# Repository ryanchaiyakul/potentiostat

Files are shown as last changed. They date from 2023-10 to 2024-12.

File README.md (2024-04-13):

# Potentiostat



I2BL potentiostat library and project.

# Goals

1. Create a library to easily program simple potentiostats for various voltammetry methods.
2. Create a collection of tools to develop future potentiostats.
3. Create a simulation suite to visualize and validate design decisions.

# Simulations

Go to the [README.md](CAD/LTSpice/README.md) in CAD/LTSpice folder.

# Tools

Go to the tools folder for a complete collection.

## CPE Models

Generate RC Train models of CPE elements to simulate how the readout circuit responds.

## PWL Voltammetry

Generate PWL files to pass into a voltage source to act as the DAC.

# Usage

```bash
# submodules are used in this repository for third party libraries
git clone --recurse-submodules git@github.com:ryanchaiyakul/potentiostat.git
```

1. Open the project in [VS Code](https://code.visualstudio.com/) with the [PlatformIO extension](https://marketplace.visualstudio.com/items?itemName=platformio.platformio-ide) installed.
2. Connect the Potentiostat to your computer by USB.
3. Navigate to the PlatformIO panel and click "Upload" or use the Command Palette (CNTL + SHIFT + P) and select "Upload".
4. Use the Serial Monitor in the terminal bar and select the baudrate of 230400.

# Features

- [x] Differential Pulse Voltammetry
- [x] Square Wave Voltammetry
- [ ] Cyclic Voltammetry
- [x] 300+ Hz SWV
- [ ] OTA Configuration
- [ ] EEPROM Persistent Configuration
- [ ] BLE Integration
- [x] Simple "Debug" Mode
- [x] Complete Analytics in "Debug" Mode
- [ ] Unit Testing Suite

# Development Guide

Create a valid class that inherits from Voltammetry defined in [Voltammetry.h](lib/Voltammetry/Voltammetry.h).

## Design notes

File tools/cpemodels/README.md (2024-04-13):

# CPE Models

Generate an RC Train that models a CPE device.

Documentation WIP

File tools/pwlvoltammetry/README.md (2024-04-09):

# PWL Voltammetry

A python tool to generate .pwl files of DAC voltages for LTSpice simulations.

## Usage

Edit config.py to the voltammetry parameters and run main.py

```bash
python main.py
```

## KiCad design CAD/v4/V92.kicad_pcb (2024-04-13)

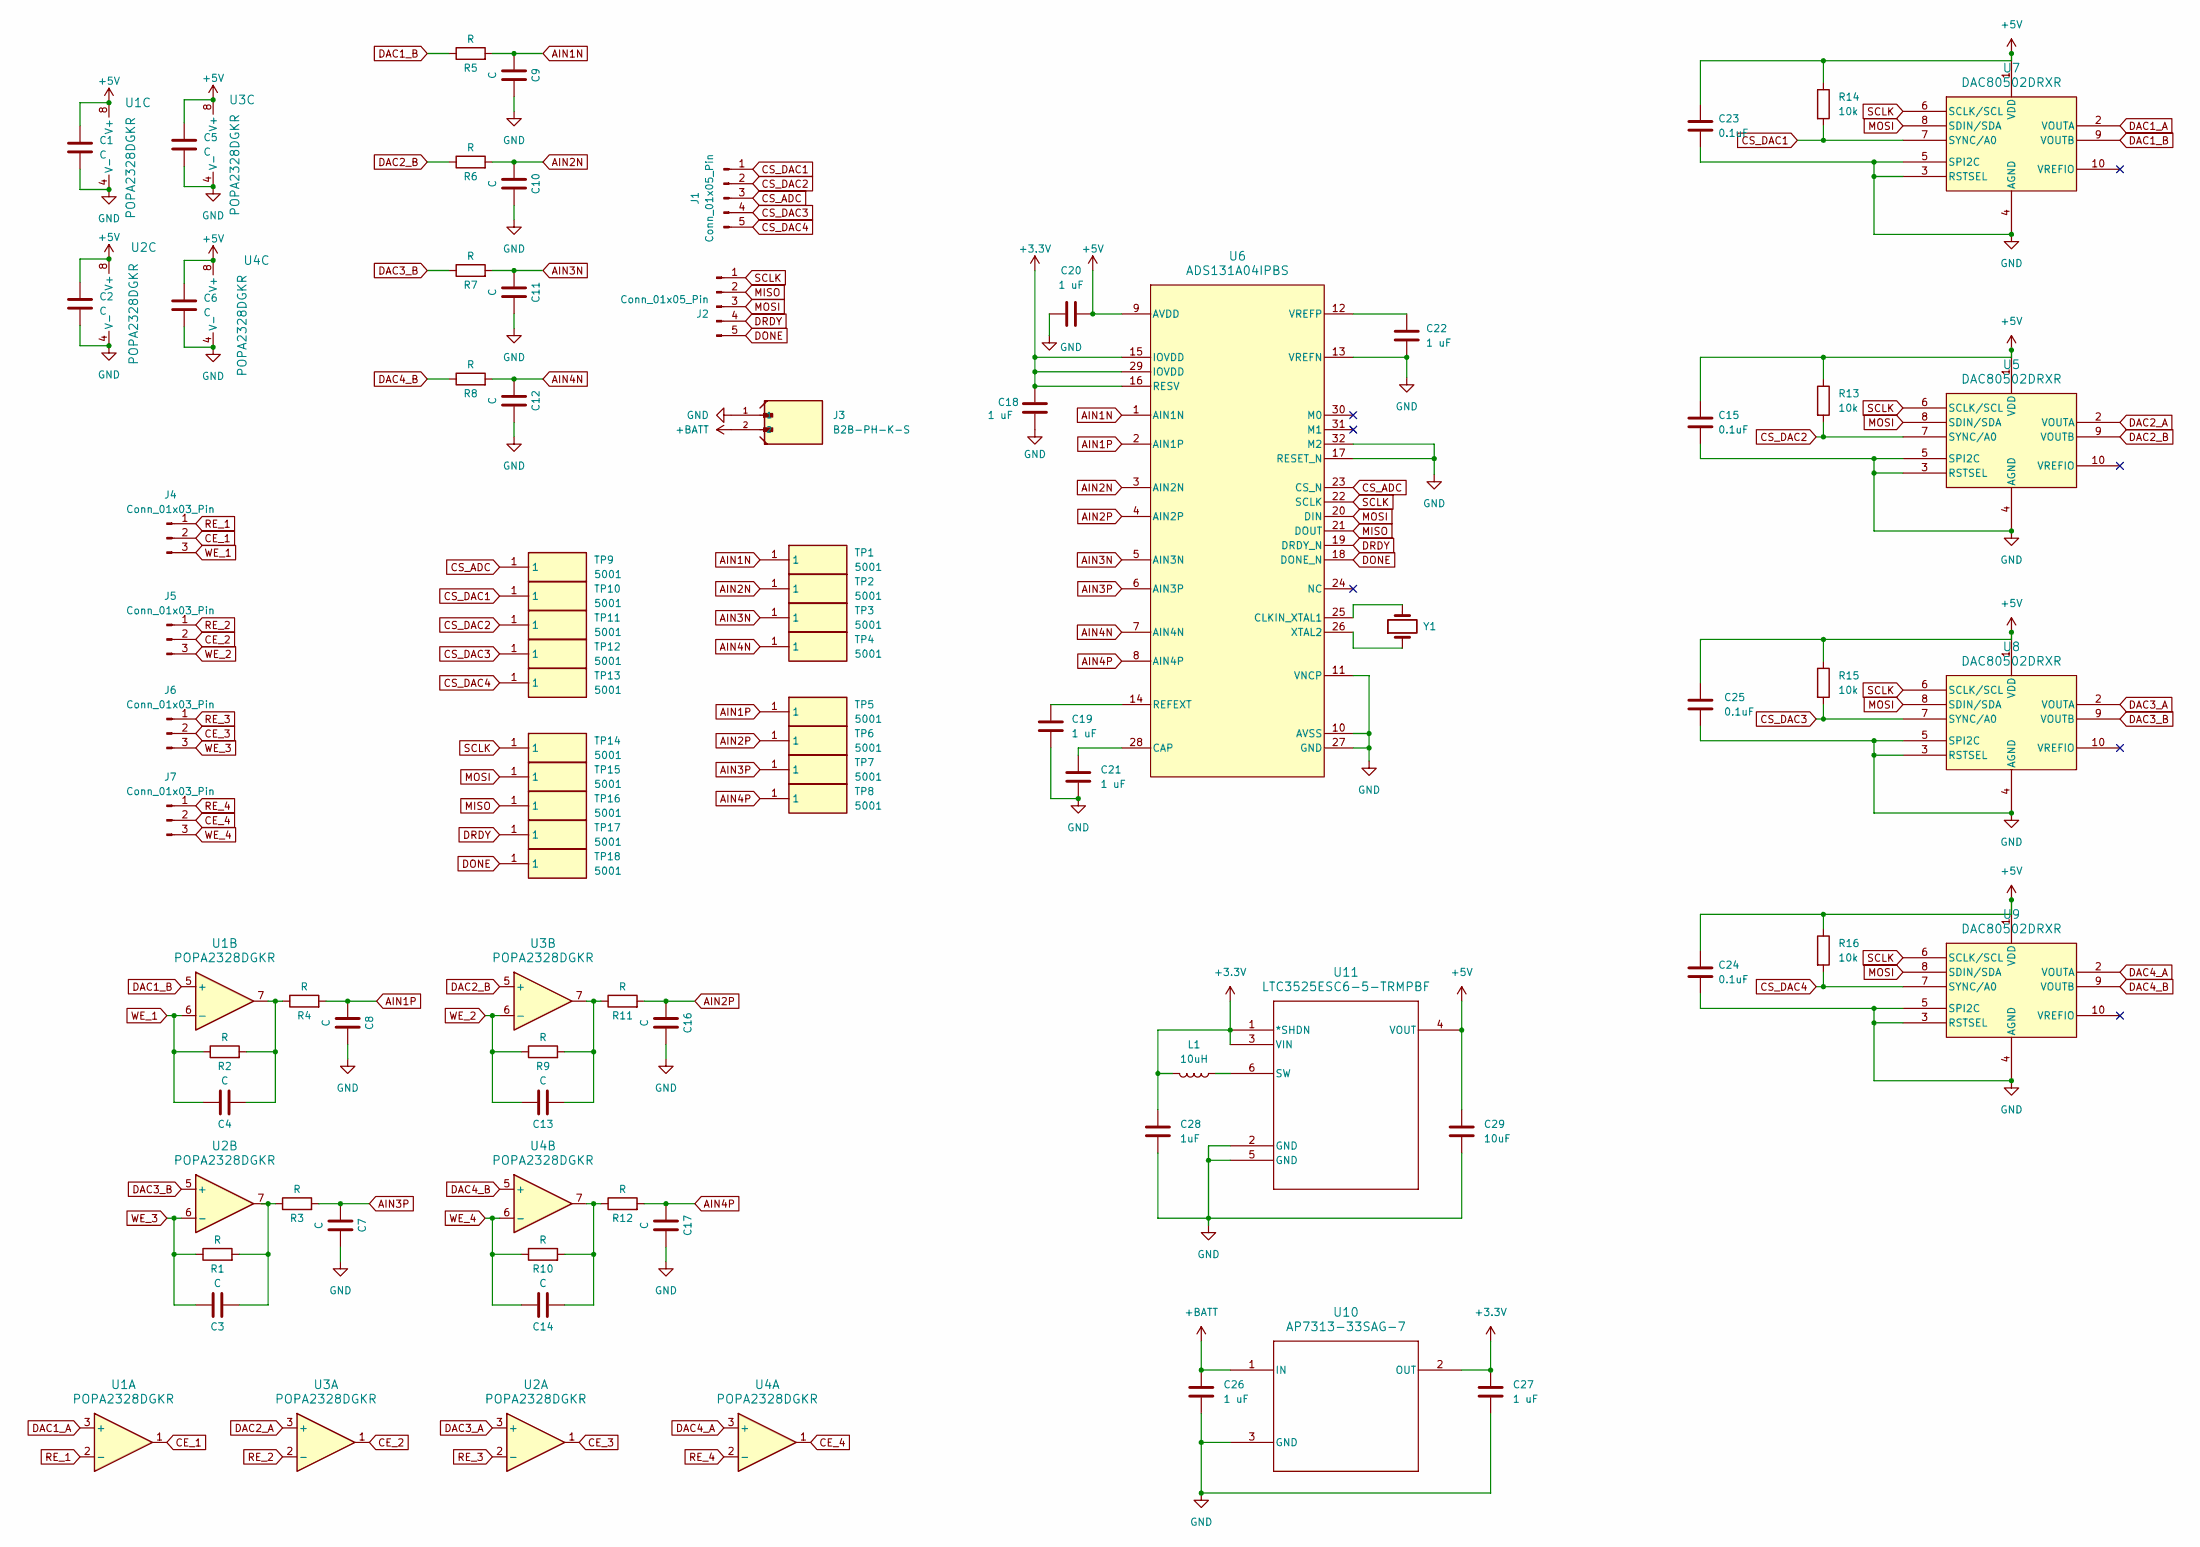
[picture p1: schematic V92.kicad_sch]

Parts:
C1, C2, C3, C4, C5, C6, C7, C8, C9, C10, C11, C12, C13, C14, C16, C17: C; C_0603_1608Metric_Pad1.08x0.95mm_HandSolder
C15, C23, C24, C25: 0.1uF; C_0603_1608Metric_Pad1.08x0.95mm_HandSolder
C18, C19, C20, C21, C22, C26, C27: 1 uF; C_0603_1608Metric_Pad1.08x0.95mm_HandSolder
C28: 1uF; C_0603_1608Metric_Pad1.08x0.95mm_HandSolder
C29: 10uF; C_0603_1608Metric_Pad1.08x0.95mm_HandSolder
J1, J2: Conn_01x05_Pin; PinHeader_1x05_P2.54mm_Vertical
J3: B2B-PH-K-S; JST_B2B-PH-K-S
J4, J5, J6, J7: Conn_01x03_Pin; PinHeader_1x03_P2.54mm_Vertical
L1: 10uH; L_0603_1608Metric_Pad1.05x0.95mm_HandSolder
R1, R2, R3, R4, R5, R6, R7, R8, R9, R10, R11, R12: R; R_0603_1608Metric_Pad0.98x0.95mm_HandSolder
R13, R14, R15, R16: 10k; R_0603_1608Metric_Pad0.98x0.95mm_HandSolder
TP1, TP2, TP3, TP4, TP5, TP6, TP7, TP8, TP9, TP10, TP11, TP12, TP13, TP14, TP15, TP16, TP17, TP18: 5001; 5000; Mouser Part Number 534-5001
U1, U2, U3, U4: POPA2328DGKR; SO8_DGK_TEX
U5, U7, U8, U9: DAC80502DRXR; SON_02DRXR_TEX
U6: ADS131A04IPBS; PBS0032A_N
U10: AP7313-33SAG-7; SOT-23_DIO
U11: LTC3525ESC6-5-TRMPBF; SC70-SC6_LIT
Y1: Crystal; Crystal_SMD_HC49-SD

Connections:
+3.3V: C18.1, C27.1, C28.1, L1.2, U6.15 (IOVDD), U6.16 (RESV), U6.29 (IOVDD), U10.2 (OUT), U11.1 (*SHDN), U11.3 (VIN)
+5V: C1.1, C2.1, C5.1, C6.1, C15.1, C20.1, C23.1, C24.1, C25.1, C29.1, R13.1, R14.1, R15.1, R16.1, U1.8 (V+), U2.8 (V+), U3.8 (V+), U4.8 (V+), U5.1 (VDD), U6.9 (AVDD), U7.1 (VDD), U8.1 (VDD), U9.1 (VDD), U11.4 (VOUT)
+BATT: C26.1, J3.2, U10.1 (IN)
AIN1N: C9.2, R5.2, TP1.1, U6.1 (AIN1N)
AIN1P: C8.2, R4.2, TP5.1, U6.2 (AIN1P)
AIN2N: C10.2, R6.2, TP2.1, U6.3 (AIN2N)
AIN2P: C16.2, R11.2, TP6.1, U6.4 (AIN2P)
AIN3N: C11.2, R7.2, TP3.1, U6.5 (AIN3N)
AIN3P: C7.2, R3.2, TP7.1, U6.6 (AIN3P)
AIN4N: C12.2, R8.2, TP4.1, U6.7 (AIN4N)
AIN4P: C17.2, R12.2, TP8.1, U6.8 (AIN4P)
CE_1: J4.2, U1.1
CE_2: J5.2, U3.1
CE_3: J6.2, U2.1
CE_4: J7.2, U4.1
CS_ADC: J1.3, TP9.1, U6.23 (CS_N)
CS_DAC1: J1.1, R14.2, TP10.1, U7.7 (SYNC/A0)
CS_DAC2: J1.2, R13.2, TP11.1, U5.7 (SYNC/A0)
CS_DAC3: J1.4, R15.2, TP12.1, U8.7 (SYNC/A0)
CS_DAC4: J1.5, R16.2, TP13.1, U9.7 (SYNC/A0)
DAC1_A: U1.3 (+), U7.2 (VOUTA)
DAC1_B: R5.1, U1.5 (+), U7.9 (VOUTB)
DAC2_A: U3.3 (+), U5.2 (VOUTA)
DAC2_B: R6.1, U3.5 (+), U5.9 (VOUTB)
DAC3_A: U2.3 (+), U8.2 (VOUTA)
DAC3_B: R7.1, U2.5 (+), U8.9 (VOUTB)
DAC4_A: U4.3 (+), U9.2 (VOUTA)
DAC4_B: R8.1, U4.5 (+), U9.9 (VOUTB)
DONE: J2.5, TP18.1, U6.18 (DONE_N)
DRDY: J2.4, TP17.1, U6.19 (DRDY_N)
GND: C1.2, C2.2, C5.2, C6.2, C7.1, C8.1, C9.1, C10.1, C11.1, C12.1, C15.2, C16.1, C17.1, C18.2, C19.2, C20.2, C21.2, C22.2, C23.2, C24.2, C25.2, C26.2, C27.2, C28.2, C29.2, J3.1, U1.4 (V-), U2.4 (V-), U3.4 (V-), U4.4 (V-), U5.3 (RSTSEL), U5.4 (AGND), U5.5 (SPI2C), U6.10 (AVSS), U6.11 (VNCP), U6.13 (VREFN), U6.17 (RESET_N), U6.27 (GND), U6.32 (M2), U7.3 (RSTSEL), U7.4 (AGND), U7.5 (SPI2C), U8.3 (RSTSEL), U8.4 (AGND), U8.5 (SPI2C), U9.3 (RSTSEL), U9.4 (AGND), U9.5 (SPI2C), U10.3 (GND), U11.2 (GND), U11.5 (GND)
MISO: J2.2, TP16.1, U6.21 (DOUT)
MOSI: J2.3, TP15.1, U5.8 (SDIN/SDA), U6.20 (DIN), U7.8 (SDIN/SDA), U8.8 (SDIN/SDA), U9.8 (SDIN/SDA)
unnamed: C3.2, R1.2, R3.1, U2.7
unnamed: C4.2, R2.2, R4.1, U1.7
unnamed: C13.2, R9.2, R11.1, U3.7
unnamed: C14.2, R10.2, R12.1, U4.7
unnamed: C21.1, U6.28 (CAP)
unnamed: U6.25 (CLKIN_XTAL1), Y1.2
unnamed: C19.1, U6.14 (REFEXT)
unnamed: C22.1, U6.12 (VREFP)
unnamed: U6.26 (XTAL2), Y1.1
unnamed: L1.1, U11.6 (SW)
RE_1: J4.1, U1.2 (-)
RE_2: J5.1, U3.2 (-)
RE_3: J6.1, U2.2 (-)
RE_4: J7.1, U4.2 (-)
SCLK: J2.1, TP14.1, U5.6 (SCLK/SCL), U6.22 (SCLK), U7.6 (SCLK/SCL), U8.6 (SCLK/SCL), U9.6 (SCLK/SCL)
WE_1: C4.1, J4.3, R2.1, U1.6 (-)
WE_2: C13.1, J5.3, R9.1, U3.6 (-)
WE_3: C3.1, J6.3, R1.1, U2.6 (-)
WE_4: C14.1, J7.3, R10.1, U4.6 (-)

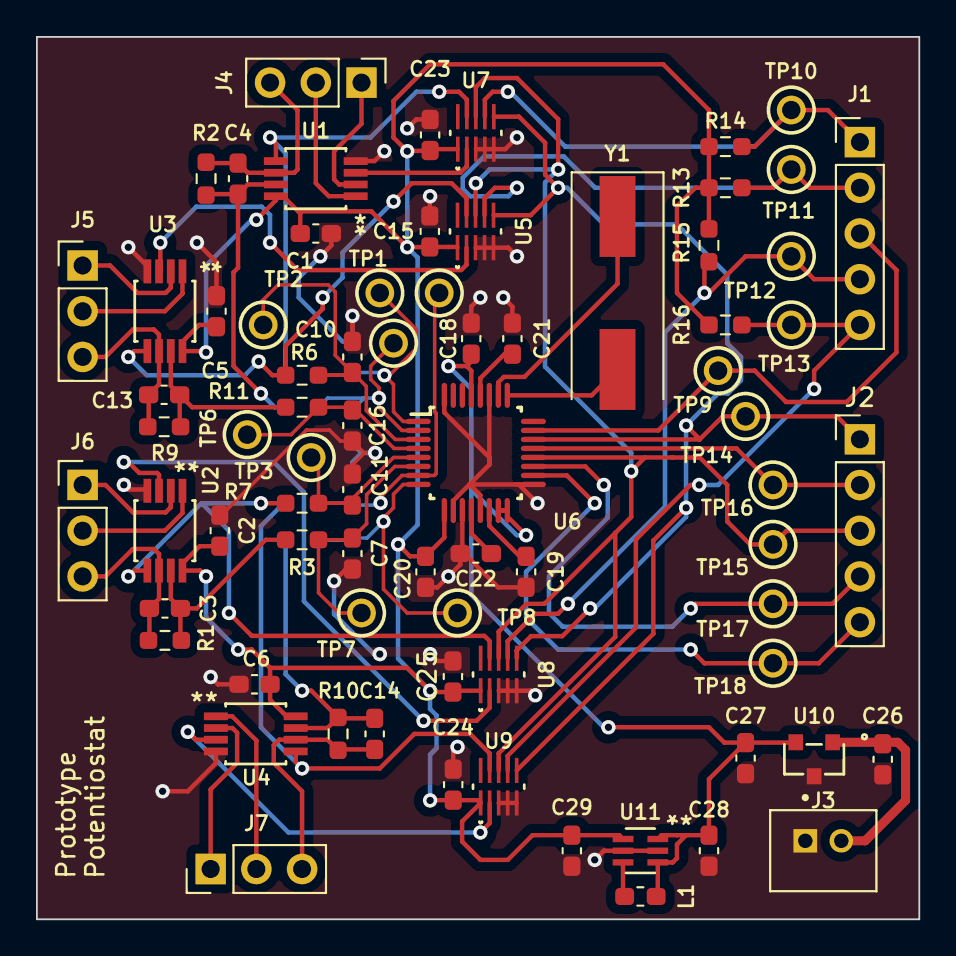
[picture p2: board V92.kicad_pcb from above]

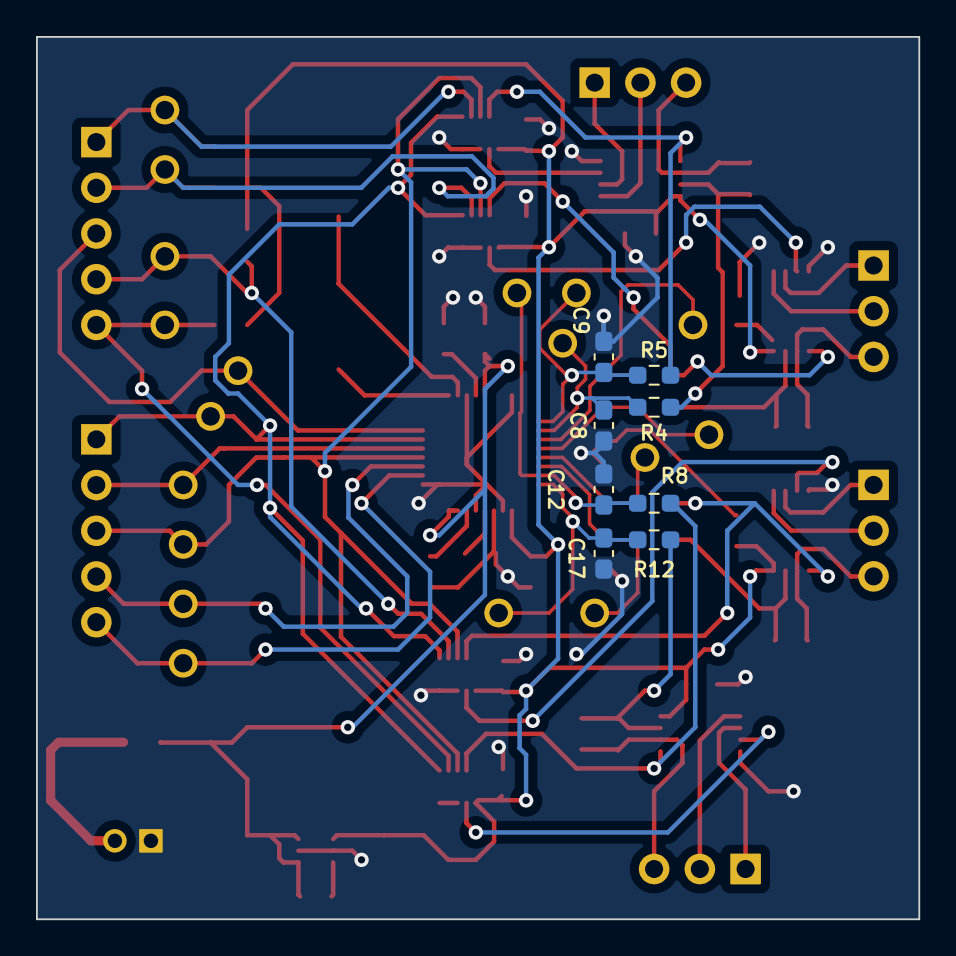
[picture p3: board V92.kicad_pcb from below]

Board: 2 copper layers, 49.0 x 49.0 mm, 83 parts (8 on the bottom side), 52 nets.

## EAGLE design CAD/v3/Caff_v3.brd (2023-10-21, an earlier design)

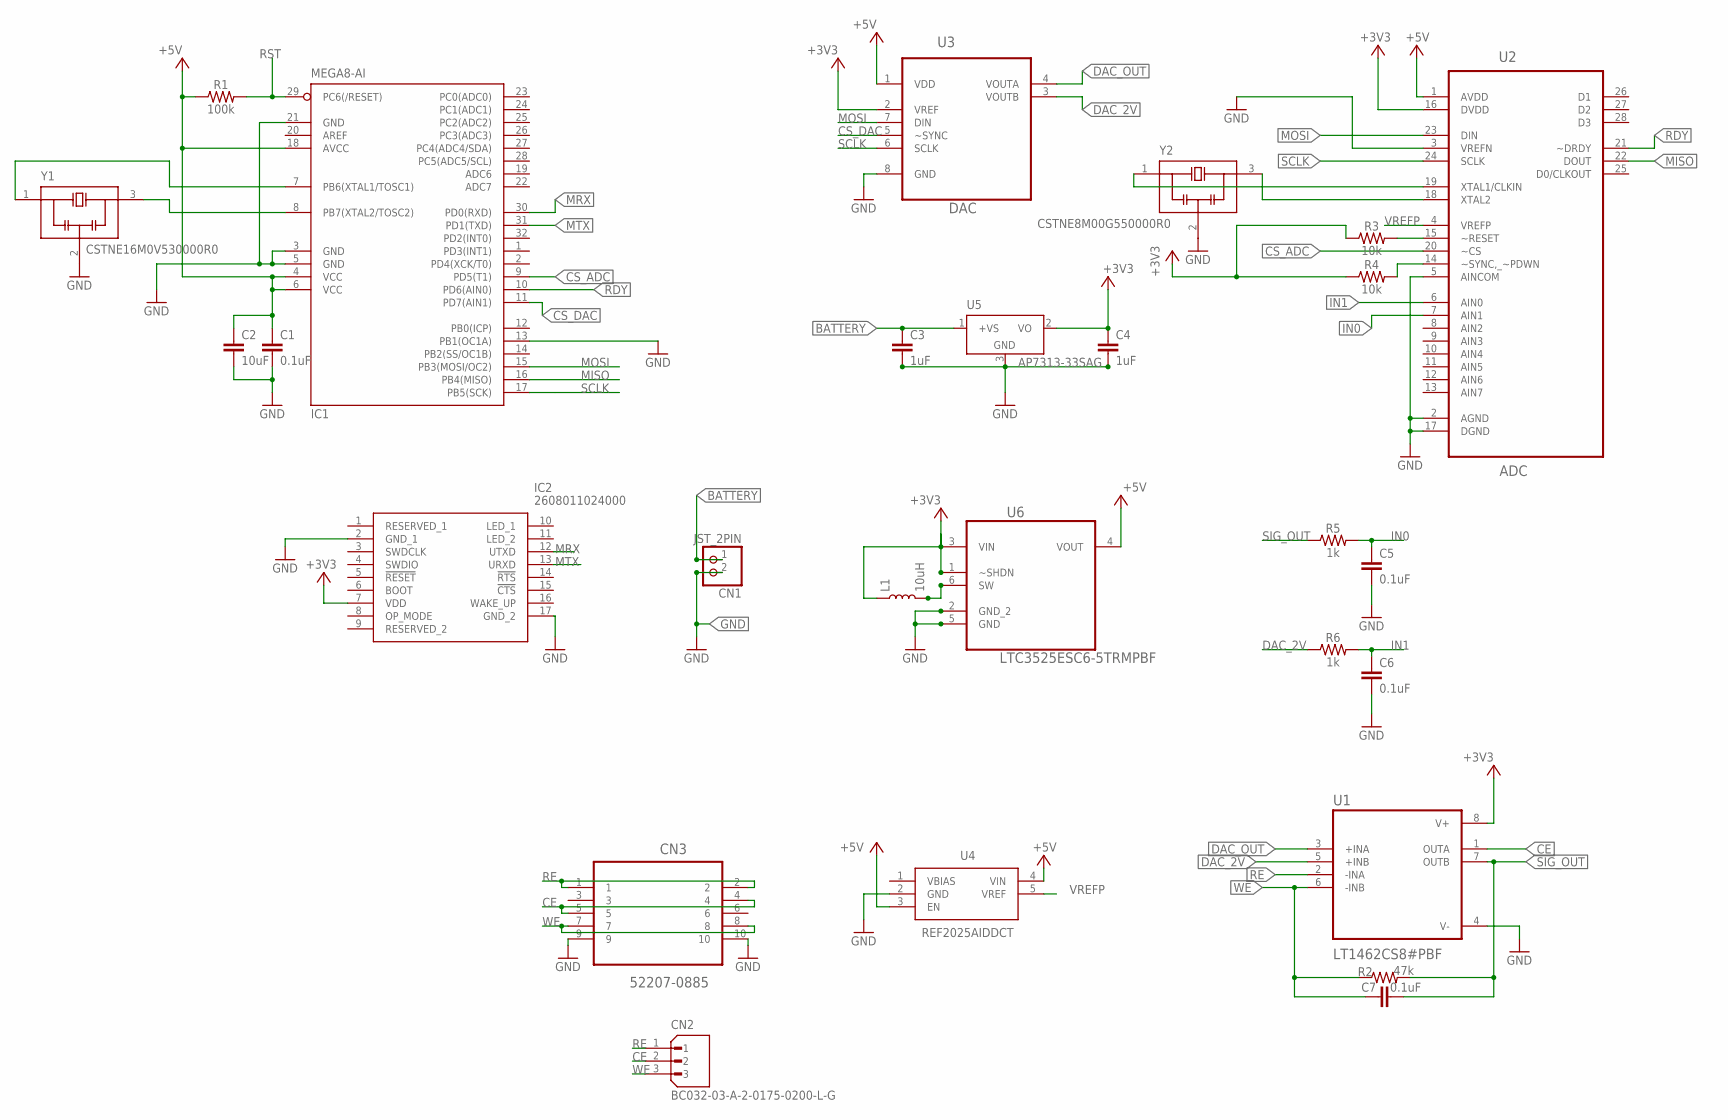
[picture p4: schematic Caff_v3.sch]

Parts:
C1, C5, C6, C7: 0.1uF; 0603
C2: 10uF; 0603
C3, C4: 1uF; 0603
CN1: JST_2PIN; JST-PH-2-SMT-RA
CN2: BC032-03-A-2-0175-0200-L-G; GCT_BC032-03-A-2-0175-0200-L-G
CN3: 52207-0885; MOLEX_52207-0885
IC1: MEGA8-AI; TQFP32-08
IC2: 2608011024000
L1: 10uH; 0603
R1: 100k; 0603
R2: 47k; 0603
R3, R4: 10k; 0603
R5, R6: 1k; 0603
U1: LT1462CS8#PBF; SOIC127P600X175-8N
U2: ADC; SOP65P780X200-28N
U3: DAC; SOP65P490X110-8N
U4: REF2025AIDDCT; SOT95P280X110-5N
U5: AP7313-33SAG; SOT23; MPN LM5008MM/NOPB
U6: LTC3525ESC6-5TRMPBF; SOT65P210X100-6N
Y1: CSTNE16M0V530000R0; OSC_CSTNE16M0V530000R0
Y2: CSTNE8M00G550000R0; OSC_CSTNE16M0V530000R0

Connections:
+3V3: C4.1, IC2.7 (VDD), L1.1, R3.1, R4.1, U1.8 (V+), U2.16 (DVDD), U3.2 (VREF), U5.2 (VO), U6.1 (~SHDN), U6.3 (VIN)
+5V: C1.1, C2.1, IC1.4 (VCC), IC1.6 (VCC), IC1.18 (AVCC), R1.1, U2.1 (AVDD), U3.1 (VDD), U4.3 (EN), U4.4 (VIN), U6.4 (VOUT)
BATTERY: C3.1, CN1.1 (2), U5.1 (+VS)
CE: CN2.2, CN3.4, CN3.5, U1.1 (OUTA)
CS_ADC: IC1.9 (PD5(T1)), U2.20 (~CS)
CS_DAC: IC1.11 (PD7(AIN1)), U3.5 (~SYNC)
DAC_2V: R6.1, U1.5 (+INB), U3.3 (VOUTB)
DAC_OUT: U1.3 (+INA), U3.4 (VOUTA)
GND: C1.2, C2.2, C3.2, C4.2, C5.2, C6.2, CN1.2 (1), CN3.9, CN3.10, IC1.3 (GND), IC1.5 (GND), IC1.13 (PB1(OC1A)), IC1.21 (GND), IC2.2 (GND_1), IC2.17 (GND_2), U1.4 (V-), U2.2 (AGND), U2.3 (VREFN), U2.5 (AINCOM), U2.17 (DGND), U3.8 (GND), U4.2 (GND), U5.3 (GND), U6.2 (GND_2), U6.5 (GND), Y1.2 (GND), Y2.2 (GND)
IN0: C5.1, R5.2, U2.7 (AIN1)
IN1: C6.1, R6.2, U2.6 (AIN0)
MISO: IC1.16 (PB4(MISO)), U2.22 (DOUT)
MOSI: IC1.15 (PB3(MOSI/OC2)), U2.23 (DIN), U3.7 (DIN)
MRX: IC1.30 (PD0(RXD)), IC2.12 (UTXD)
MTX: IC1.31 (PD1(TXD)), IC2.13 (URXD)
unnamed: IC1.7 (PB6(XTAL1/TOSC1)), Y1.1 (IN)
unnamed: IC1.8 (PB7(XTAL2/TOSC2)), Y1.3 (OUT)
unnamed: U2.19 (XTAL1/CLKIN), Y2.1 (IN)
unnamed: U2.18 (XTAL2), Y2.3 (OUT)
unnamed: R3.2, U2.15 (~RESET)
unnamed: L1.2, U6.6 (SW)
unnamed: R4.2, U2.14 (~SYNC,_~PDWN)
RDY: IC1.10 (PD6(AIN0)), U2.21 (~DRDY)
RE: CN2.1, CN3.1, CN3.2, U1.2 (-INA)
RST: IC1.29 (PC6(/RESET)), R1.2
SCLK: IC1.17 (PB5(SCK)), U2.24 (SCLK), U3.6 (SCLK)
SIG_OUT: C7.2, R2.2, R5.1, U1.7 (OUTB)
VREFP: U2.4 (VREFP), U4.5 (VREF)
WE: C7.1, CN2.3, CN3.7, CN3.8, R2.1, U1.6 (-INB)

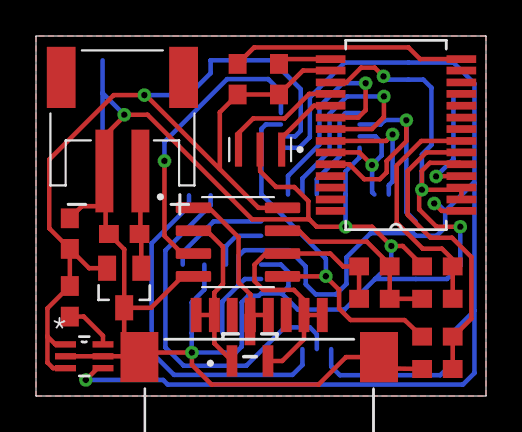
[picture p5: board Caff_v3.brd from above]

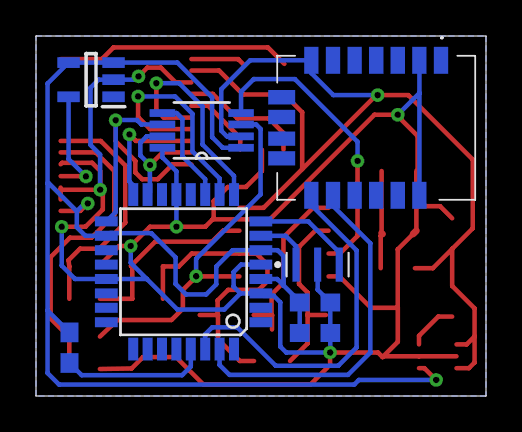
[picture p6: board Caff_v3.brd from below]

Board: 2 copper layers, 25.0 x 20.0 mm, 27 parts (8 on the bottom side), 29 nets.

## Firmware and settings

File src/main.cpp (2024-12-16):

#include <Arduino.h>
#include <SPI.h>

#include <ADS1256.h>
#include <ADS131A04.h>
#include <DAC8552.h>
#include <DAC80502.h>
#include <DPV.h>
#include <SWV.h>

#include <LMP91000.h>

// Baud Rate
#define BAUD_RATE 230400 // 115200 or 230400 for DPV

// Pinout
#define RDY 3
#define CS_adc 8
#define DRDY 9
#define CS_dac 10
#define DIN 11  // MISO
#define DOUT 12 // MOSI
#define SCLK 13 // SCLK

#define REFDACMV 2499
#define AMPOFFSET 0

#define WEMV 1800
#define MINMV WEMV - REFDACMV // WE-RE lowest voltage
#define MAXMV WEMV            // WE-RE highest voltage

#define KERNELSIZE 8 // Samples during sample period

// Modes
#define SERIAL_MODE 0
#define EXP_MODE 1
#define DEB_MODE 2

// DPV Setting Sources (And Electrochemical Workstation)
// https://pineresearch.com/shop/kb/software/methods-and-techniques/voltammetric-methods/differential-pulse-voltammetry-dpv/

// DPV Settings

// All in mV
int dpvStartMV = 100;
int dpvEndMV = -250;
int dpvIncrE = 5; // Sign calculated later
int dpvAmplitude = 25;

// 10ms granularity (us)
unsigned long dpvPulseWidth = 100000;
unsigned long dpvPulsePeriod = 500000; // Includes pulse
unsigned long dpvQuietTime = 2000000;  // Hold reference at dpvTrueStartMV for x us
unsigned long dpvRelaxTime = 2000000;  // Hold reference at dpvTrueEndMV for x us

unsigned long dpvSamplingOffsetUS = 1670;

// SWV Setting Sources
// https://pineresearch.com/shop/kb/software/methods-and-techniques/voltammetric-methods/square-wave-voltammetry/

// SWV Settings

// All in mV
int swvStartMV = -50;
int swvVerticesMVs[4] = {0}; // up to 4 vertices
int swvEndMV = -450;
int swvIncrE = 1;
int swvAmplitude = 25;

int swvVertices = 0;

// 10ms granularity (us)
unsigned long swvFrequency = 60;     // Hz <= 200 Hz
unsigned long swvQuietTime = 2000000; // Hold reference at swvTrueStartMV for x us
unsigned long swvRelaxTime = 2000000; // Hold reference at swvTrueEndMV for x us
unsigned long swvSamplingOffsetUS = 1000;

// Loop variables
int8_t state = 0;
Voltammetry *method;
UpdateStatus status;
double mv[2];
bool high_low = true;  // false on low cycle
bool is_ready = false;

// Debug
bool debug_f = false;
unsigned long start_time;
unsigned count;

ADS131A04 adc(CS_adc, DRDY);
DAC80502 dac(CS_dac, REFDACMV);

DPV dpv(dpvStartMV,
        dpvEndMV,
        dpvIncrE,
        dpvAmplitude,
        dpvPulseWidth,
        dpvPulsePeriod,
        dpvSamplingOffsetUS,
        dpvQuietTime,
        dpvRelaxTime,
        MINMV,
        MAXMV);

SWV swv(swvStartMV,
        swvEndMV,
        swvVerticesMVs,
        swvVertices,
        swvIncrE,
        swvAmplitude,
        swvFrequency,
        swvSamplingOffsetUS,
        swvQuietTime,
        swvRelaxTime,
        MINMV,
        MAXMV);

void selectDPV()
{
  method = &dpv;
}

void selectSWV()
{
  method = &swv;
}

void serialCMD(byte cmd)
{
  // Single character corrresponds with a command
  switch (cmd)
  {
  // Begin experiment
  case 'b':
  case 'B':
    if (debug_f)
    {
      state = DEB_MODE;
      start_time = micros();
    }
    else
    {
      state = EXP_MODE;
      //adc.printCallibration();
    }
    high_low = true;
    method->reset();
    break;
  // DPV mode
  case 'd':
  case 'D':
    selectDPV();
    break;
  // SWV mode
  case 's':
  case 'S':
    selectSWV();
    break;
  // CallibrateADS
  case 'c':
  case 'C':
    adc.callibrate();
    break;
  case 'v':
  case 'V':
    debug_f = !debug_f;
    if (debug_f) {
      Serial.println("Debugging mode enabled");
    }
    break;
  default:
    break;
  }
}

void setup()
{
  Serial.begin(BAUD_RATE);
  dac.init();
  // TODO: Add synchronized setB/setA to prevent the cell from excessive voltage at startup
  dac.setB(WEMV); // Bias point
  dac.setA(WEMV);
  adc.init();

  // Default DPV
  selectDPV();
}

void potentiostatMain() {
  switch (state)
  {
  case SERIAL_MODE:
    if (Serial.available())
    {
      serialCMD(Serial.read());
    }
    break;
  case EXP_MODE:
    status = method->update();
    switch (status)
    {
    case NONE:
      // TODO: Implement working burst mode
      if (is_ready) {
        Serial.println(mv[0] - mv[1]);
        is_ready = false;
      }
      break;
    case SHIFTV:
      dac.setA(WEMV - method->getVoltage());
      break;  
    case SAMPLE:
      if (high_low) {
        mv[0] = analogRead(A3) * (5.0 / 1024.0);
      }
      else {
        mv[1] = analogRead(A3) * (5.0 / 1024.0);
        is_ready = true;
      }
      high_low = !high_low;
      break;
    case DONE:
      // Send last sample if there was not time to send it
      state = SERIAL_MODE;
      break;
    }
    break;
  case DEB_MODE:
  {
    // Does not actuate DAC or ADC, just reports what should happen when
    status = method->update();
    switch (status)
    {
    case NONE:
      break;
    case SHIFTV:
      Serial.print(micros() - start_time);
      Serial.print(',');
      Serial.println(method->getVoltage());
      break;
    case SAMPLE:
      // Count # of sent samples and timing
      Serial.print(micros() - start_time);
      Serial.print(',');
      Serial.println("Sample");
      count++;
      break;
    case DONE:
      state = SERIAL_MODE;
      break;
    }
  }
  break;
  }
}

void test() {
  Serial.println("1.0");
  dac.setA(1.0);
  delay(1000);
  Serial.println("1.4");
  dac.setA(1.4);
  delay(1000);
}

/**
   DO NOT MODIFY

   Change DPV/SWV Settings above (or in Serial)
*/
void loop()
{
  //Serial.println(adc.readReg(0x07));
  //delay(1000);
  potentiostatMain();
  //Serial.println(analogRead(A3) * (5.0 / 1024.0), 4);
  //delay(50);
}

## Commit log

2023-10-21 initial commit
    Working DPV and SWV configured by fixed variables. Contains basic
    LTSpice for TransAmp calculations. Use with VS Code and Platform.io.
    [main.cpp]
2023-10-21 CAD populated
    Moved transAmp into folder and brought back v3 Eagle design
    [Caff_v3.brd, Caff_v3.sch]
2024-01-12 migrated LTSpice files
    Moved and renamed LTSpice files into corresponding folder with .plt
    forms
    [Potentiostat.kicad_pcb, Potentiostat.kicad_sch]
2024-04-09 working DAC80502
    The SPI works but it is intermittent
    [Analog.SchDoc, LMP9100.PcbDoc, LMP9100.PrjPcb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]
2024-04-13 cleaned up workspace
    Added documentation and finalized folder structure
    [Potentiostat.kicad_pcb, Potentiostat.kicad_sch, V92.kicad_pcb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]
2024-04-26 pushing wip LMP910000
    [Analog.SchDoc, LMP91000 BLE.PrjPcb]

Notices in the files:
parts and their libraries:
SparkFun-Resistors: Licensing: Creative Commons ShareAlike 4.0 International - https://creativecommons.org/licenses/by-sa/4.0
